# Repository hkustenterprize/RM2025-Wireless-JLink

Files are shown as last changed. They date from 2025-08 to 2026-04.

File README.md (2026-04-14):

# 基于嵌入式 Linux 的无线 JLink 烧录器
Wireless JLink-OB based on Allwinner V3S
基于全志科技 V3S 的无线 JLink-OB 烧录器. **完美支持 Ozone, Keil, STM32CubeIDE 等开发软件.**
在网络状态良好情况下, Ozone 内最多可以以 1KHZ Graph 3-4 个变量. 或者以 5Hz 刷新率观测约 50 个值.

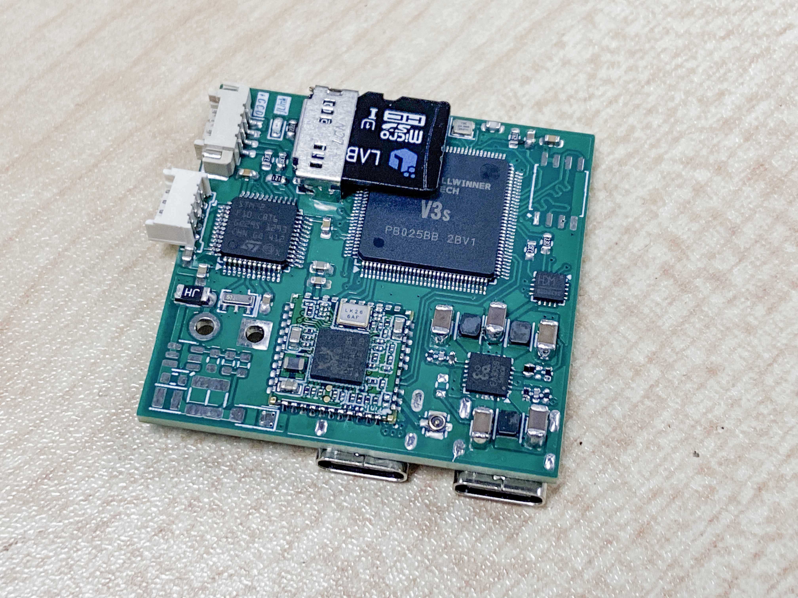
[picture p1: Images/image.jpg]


实现原理: 在 V3S 上运行自编译的 Linux 系统, 并运行 JLinkRemoteServer 共享挂载在 V3S USB 上的 JLink-OB. 板卡通过 RTL8723 SDIO 网卡联网, 处于同一局域网的电脑可通过输入无线烧录器的 IP 地址进行连接.

**主要参数**
|参数||
|:--|:--|
|尺寸|41x39x5mm|
|JLink版本|JLink-OB|
|接口|4线 SWD接口|
|无线连接距离|5-10m|

**硬件选型**
|参数||
|:--|:--|
|JLink MCU|STM32F103CB|
|嵌入式 Linux Soc|全志 V3S|
|网卡型号|RTL8723|
|电源管理芯片|EA3059|

**电源树**
系统电源较为复杂, 共有 +24V, +5V, +3V3, +3V0, +1V8, +1V2 几种不同电压. 主要由 EA3059 (或 EA3059C) 产生. 其中, V3S 内部供电由蓝色标出, 板上其他外设供电由黄色标出.
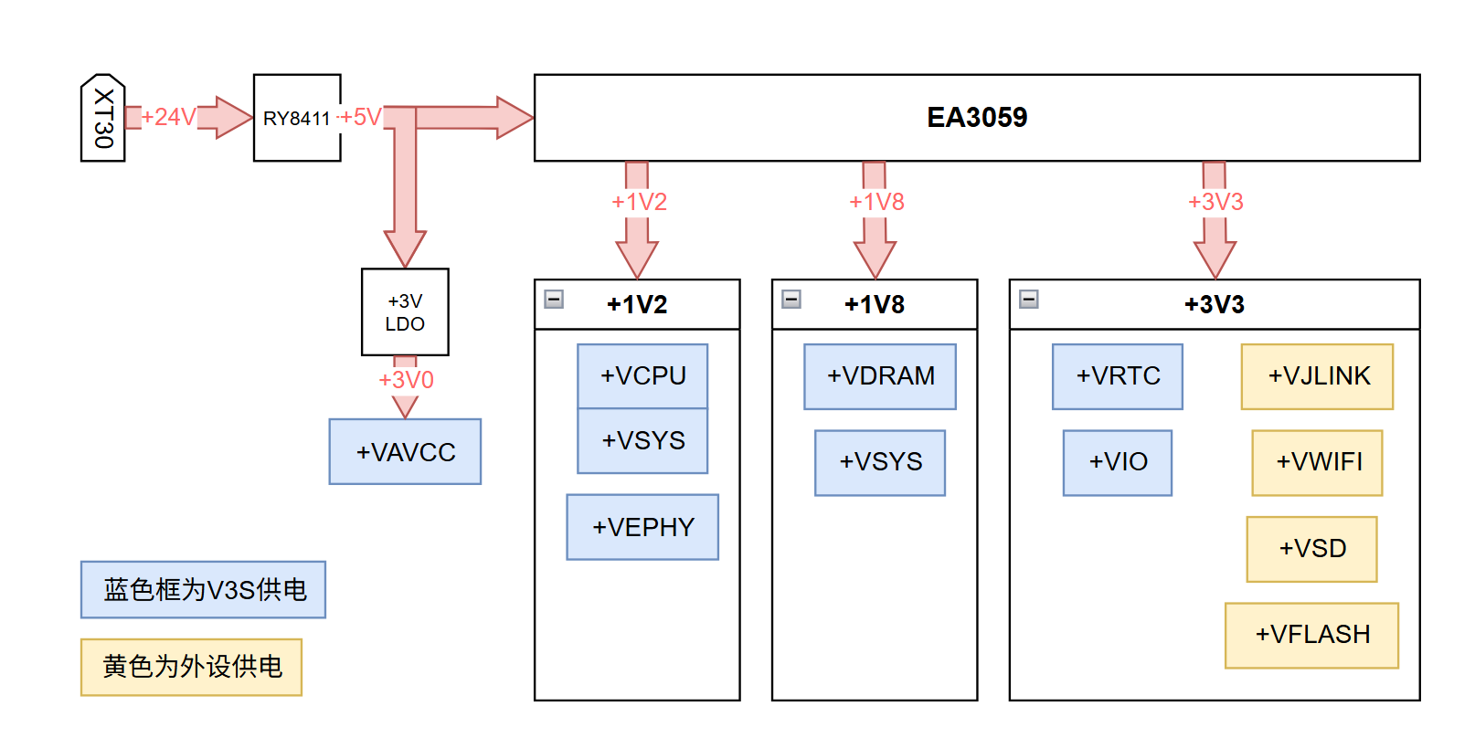
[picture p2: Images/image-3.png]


**硬件框图**
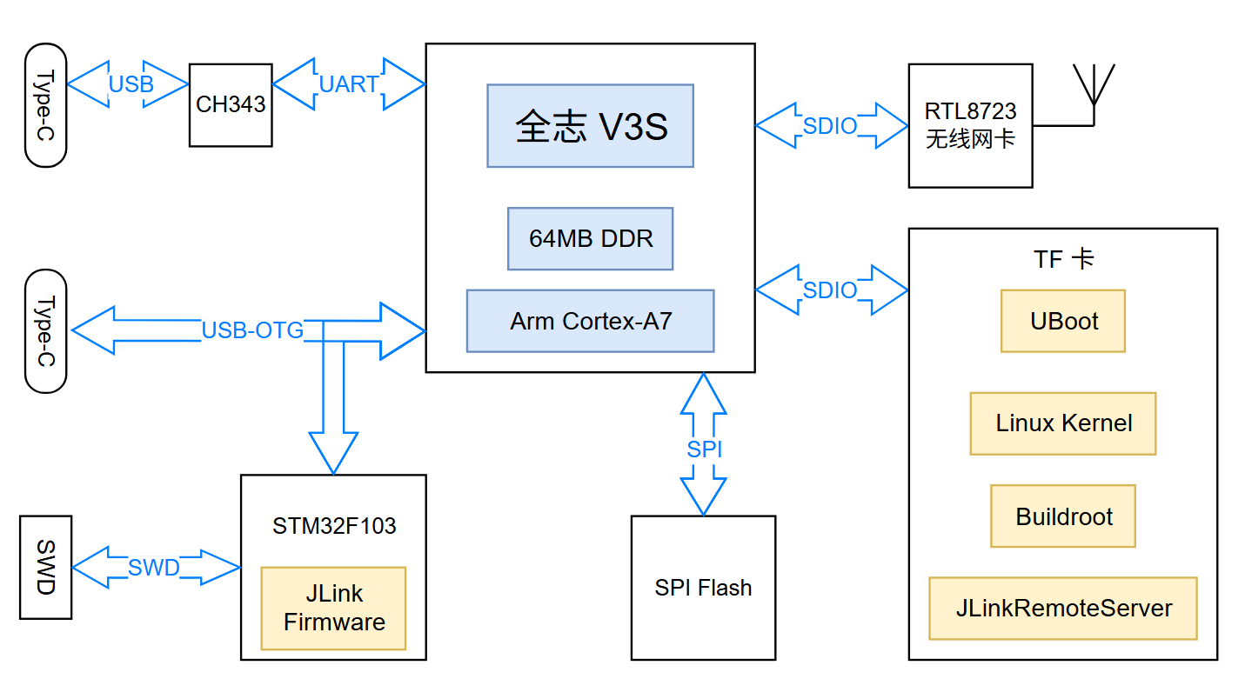
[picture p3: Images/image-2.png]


# 使用方法
> 请注意, 当前版本 SWD 接口的引脚定义与常见 SWD 引脚定义相反. 是笔者的设计失误. 请使用同向 1.25mm 同向线或手动修正线序.

1. 根据下文的固件烧录方法, 烧录 JLink 与 TF 卡固件. 并将 TF 卡插入板子上的 TF 卡座.
2. 电脑打开串口调试助手, 用 Type-C 线连接电脑与 **板子上标有 UART 的 Type-C 座**, 在串口调试助手上打开 CH343 串口. **波特率选择 115200, 数据位 8, 停止位 1, 校验位 None, 无流控**
3. 若硬件一切正常, 固件烧录正确, 将会看到串口调试助手输出以下内容:

```
U-Boot 2017.01-rc2-00057-g32ab1804cd (Sep 30 2024 - 18:54:30 +0800) Allwinner Technology

CPU:   Allwinner V3s (SUN8I 1681)
Model: Lichee Pi Zero
DRAM:  64 MiB

...
Found U-Boot script /boot.scr
reading /boot.scr
...
Starting kernel ...

[    0.000000] Booting Linux on physical CPU 0x0

...
Welcome to ENTERPRIZE buildroot.
```

实际输出可能与给出的示例略有差别, 以打印出 Welcome to ENTERPRIZE buildroot. 为一切正常的标准.
此时的界面为 Linux 命令行登录界面. 账号为 **root**, 密码为 **baoqi**

**Wifi 配置**
首次启动成功后, 请参照如下步骤连接 wifi. 需要注意的是, 路由器需要选择 WPA-EAP/WPA-PSK 加密方式. 其他加密方式需要对应修改 /etc/wpa_supplicant.conf 且笔者实测兼容性较差, 在部分路由器出现认证失败问题无法联网.

1. 编辑 /etc/wpa_supplicant.conf
```conf
ctrl_interface=/var/run/wpa_supplicant
ctrl_interface_group=0
ap_scan=1
network={
    ssid="Your SSID"
    scan_ssid=1
    key_mgmt=WPA-EAP WPA-PSK IEEE8021X NONE
    pairwise=TKIP CCMP
    group=CCMP TKIP WEP104 WEP40
    psk="Your Wifi Password"
    priority=5
}
```

2. 打开 /etc/init.d/wirelessJLinkAutoScript.sh, 并取消相关注释, 最终结果为:
```bash
#!/bin/sh
insmod /lib/modules/r8723bs.ko
ifconfig wlan0 up
wpa_supplicant -B -c /etc/wpa_supplicant.conf -i wlan0
sleep 3s
udhcpc -i wlan0
/root/JLinkARM/JLinkRemoteServerCLExe
```
3. 重启板子, 此时通过串口调试助手观察, 应该会打印出板子对应 IP, 需要并记录此 IP. 同时会显示 Waiting for client connections.. 相关文字, 代表 J-Link Remote Server 已经正常运行.
4. 通过 **交叉 1.25 4Pin 线** 连接无线烧录器 SWD 输出口与目标板.
> 请注意, 当前版本 SWD 接口的引脚定义与常见 SWD 引脚定义相反. 是笔者的设计失误. 请使用同向 1.25mm 同向线或手动修正线序.

5. 以 Ozone 为例, 在同一个局域网内, 输入无线烧录器的 IP 地址即可连接目标板.
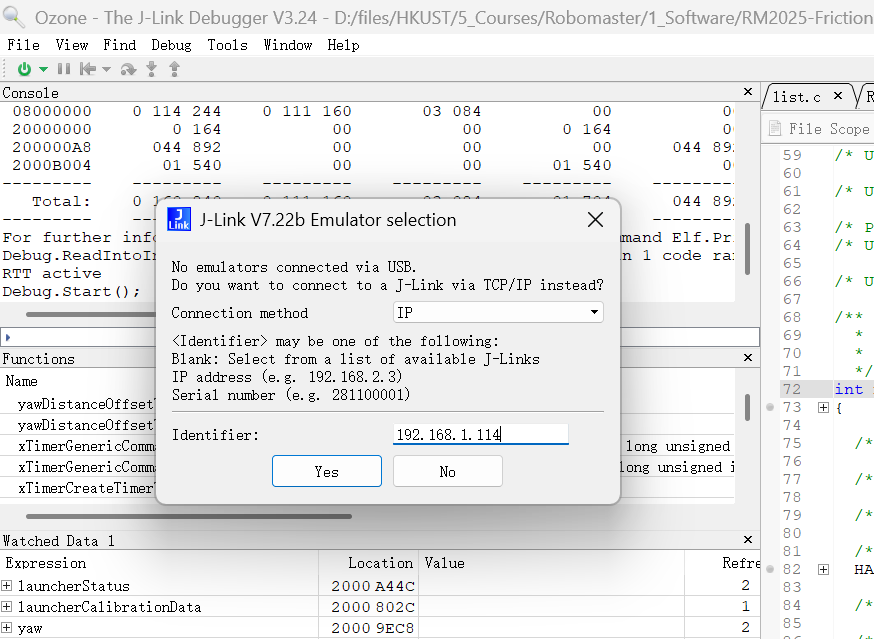
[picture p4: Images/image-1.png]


> 无线烧录器在车上使用时需要通过 Type-C 或者 XT30 供电. 经测试, 若目标板 SWD 接口有反向供电功能, 不对无线烧录器额外供电也能进行烧录, 但为确保使用稳定性, 仍建议对无线烧录器进行单独供电.

# 固件烧录
目前仅提供 TF 卡烧录相关二进制以及 TF 卡固件编译教程, SPI NOR Flash 镜像仍在调试中. 板子上的 SPI NOR Flash 可以不焊.
> 固件将与编译教程仍在整理中, 将稍后一同开源

**JLink 固件烧录**
参见笔者另一个开源 [【RM2025-地表最小 JLink 开源】香港科技大学 ENTERPRIZE 战队](https://bbs.robomaster.com/article/760967) 中给出的固件以及烧录方法.

**TF 卡固件烧录**
TF 卡要求: 容量 >= 256MByte. 读写速度无要求.
提供完整的固件 dump, 在 ./Firmware/RM2025-WirelessJLink.zip 作为参考. 其 dts, Kernel 等部分可直接复制使用.
Linux 下解压后直接用 dd 命令烧录 ./Firmware/RM2025-WirelessJLink.bin 到 TF 卡.
注意烧录 ./Firmware/RM2025-WirelessJLink.bin 之后需要手动修改网卡 ID 才能正常联网. 具体可根据自动脚本联网时的报错信息自行搜索解决.

# 固件编译
请参考 [固件编译教程](./Docs/LinuxCompileGuide.md)
其中详细地介绍了如何在 
- [荔枝派 UBoot](https://github.com/Lichee-Pi/u-boot/tree/v3s-current)
- [主线 Linux 内核](https://github.com/torvalds/linux) 
- [主线 Buildroot](https://buildroot.org/downloads/buildroot-2019.08.tar.gz)
的基础上一步步配置并编译出我们所需的 UBoot, 最简 Linux Kernel, 最简 Buildroot.

其中也包含了对全过程工具链, 启动流程, 配置思路, Linux 内核设备树, 关于 JLinkRemoteServer 的研究, RTL8723 无线网卡驱动配置, 固件加载等诸多基础内容的介绍.
凝聚了笔者全过程的踩坑经验, 或许是入门嵌入式 Linux 不错的参考.

# 未来更新
已知的硬件 bug:
- SWD 接口的引脚定义与常见 SWD 引脚定义相反. 是笔者的设计失误. 请使用同向 1.25mm 同向线或手动修正线序.

未来版本中会做如下更新:
- 增加锂电池充放电管理, 使之不再依赖于外部供电
- 修改 JLink 相关电路, 缩小体积
- 减少 V3S 滤波电容, 缩小体积

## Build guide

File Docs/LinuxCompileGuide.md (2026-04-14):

# V3S 简介与固件编译教程

[TOC]

# 引文
本教程第一部分是嵌入式 Linux 综述, 简要对比介绍主流开发板的方案, 并简述嵌入式 Linux 的开发逻辑. 第二部详细展开 **全志 V3S** 的开发流程与技术细节. 

---

**嵌入式 Linux 主流方案介绍** 时下, 树莓派, 香橙派, 荔枝派, 香蕉派等开发板市场呈现出 **百花齐放** 的繁荣景象. 其中, 基于树莓派 Raspberry Pi, 瑞芯微 Rockchip, 全志 Allwinner, 晶晨 Amlogic 等厂商 SoC 的开发板最为丰富. 此外, 主流开发板也有 ESP32, K210 等. 主要差异对比如下:

**Linux 开发板**
| 厂商 | 代表 SoC  | 性能定位 | 典型开发板 | 特点 |
|--|--|--|--|--|
|树莓派 Raspberry Pi| 博通 BCM27xx | 中高端 (1.5-2GHz) | 树莓派 4/5 | 生态优秀, 社区活跃 |
|瑞芯微 Rockchip| RK3588, RK3506 | 高端 (~2.4GHz) | Radxa ROCK 5B | 高性能视频编解码, NPU |
|全志 Allwinner| H616/D1/F1C200s/V3S | 中低端 (1.5-1.8GHz)| 香橙派, 荔枝派 | 生态较好, 社区适配完善 |
|晶晨 Amlogic| A311, S905 | 中端 (~2.0GHz) | Khadas VIM3 | 高性能 NPU, 视频处理. 生态一般. |

**RTOS 开发板**
| 厂商 | 代表 SoC  | 性能定位 | 典型开发板 | 特点 |
|--|--|--|--|--|
| 乐鑫 Espressif | ESP32 | 边缘无线通信 (240MHz) | 安信可 ESP 模块 | Wi-Fi/蓝牙双模, 高性价比 |
| 嘉楠科技 | K210 | 边缘AI (400MHz) | CamMV, MaixCAM | KPU神经网络加速, 边缘视觉 |

---

其中, 全志系列 soc 生产年份较早, 开源社区适配完善. 且全志推出了部分高性能且硬件友好的甜品款 SoC, 例如 F1C200s, V3s, V831, V851s, 其内部集成了 DDR 内存, 无须外部高速布线; 不采用 BGA 封装, 焊接友好, 4 层甚至 2 层板即可布下. 我们的最终目标是运行 JLinkRemoteServer, 并尽可能选择便宜低端的 SoC. F1C200s 没有 FPU 无法运行 JLinkRemoteServer, V831 已停产价格高. V3s 在某二手平台上价格为 10元/片 拆机带板. 因此笔者选择了 V3s. 

**全志 V3s** 封装内内有一个 ARM Cortex-A7 CPU(32 位) 以及 64MB DDR 内存. 特色是包含 CSI 相机接口, 与 RGB 屏幕接口. 设计之初主要应用于相机类产品, 如行车记录仪, 摄像头, 卡拉 OK 中控等. 沿用此思路, V3S 可成为飞镖视觉制导/无线调参方案之一. 但受限于 Linux 平台开发难度, 未进行进一步研发.

软件开发方面, V3S 基于 ARM Cortex 架构, 因此其开发方式与 STM32 有诸多相似之处. 本教程也将与 STM32 开发流程进行对比解析, 以方便了解 STM32 嵌入式开发技术的同学快速入门. 软件适配上主要有全志官方 Camdriod SDK, 主线 Linux, 第三方 XBoot 等裸机框架等丰富选择. 下面是对其简要的介绍.

|软件框架|简介|
|--|--|
|全志官方 Camdriod SDK|内核版本 3.4, 官方主推, 摄像头驱动适配好, 但开发资料少|
|主线 Linux|资料丰富但复杂度高|
|XBoot 等裸机框架|与 STM32 开发高度相似, 但社区支持较差, 无法直接运行 JLinkRemoteServer|

> **名词解释**
> 主线 Linux: 主要指主线内核 https://github.com/torvalds/linux, 是不同发行版修改的源头, 是 Linux 内核的主干与官方发布.
> 裸机: 没有操作系统, 直接运行程序.

笔者选择在 V3S 上运行 **主线 Linux**, 主要是出于学习目的与信仰.

# V3S
**参考资料列表**
- [荔枝派官方资料](https://wiki.sipeed.com/soft/Lichee/zh/Zero-Doc/System_Development/uboot_build.html)
- [CSDN RTL8723 Wifi 模块配置教程](https://blog.csdn.net/qq_28877125/article/details/125092933)

# 软件框架
固件主要包含三个部分, UBoot, Linux Kernel, Buildroot. 
- **UBoot** 为 bootloader, 其功能是初始化 ddr, 初始化时钟等. 同时, UBoot 会从引导介质, 如 TF 卡, SPI Flash, NAND Flash 等处搜索可启动的介质, 并从中加载 Kernal 并运行. 同时也会向内核传递一些启动参数. 详见后文 Uboot 编译部分.
- **Kernel** 即内核, 本质是一个巨大的程序. 负责管理计算机硬件资源, 并为应用程序提供接口.
- **Buildroot** 用来构建根文件系统. 即构建我们在根目录下看到的 /var, /opt 等文件夹. 

你可以跟着下文一步步进行配置编译与烧录.

相关链接:
- [荔枝派 UBoot](https://github.com/Lichee-Pi/u-boot/tree/v3s-current)
- [主线 Linux 内核](https://github.com/torvalds/linux) 
- [主线 Buildroot](https://buildroot.org/downloads/buildroot-2019.08.tar.gz)

# 环境配置
本教程基于 Ubuntu 22.04(x86_64) 平台. 笔者实测 WSL, 虚拟机也可正常编译但速度奇慢. 在 13900 平台上全量 rebuild 需要约 20 分钟.

安装编译所需的基本依赖
```bash
sudo apt install git wget make gcc flex bison libssl-dev bc kmod
```

安装 **交叉编译工具链**. 编译平台架构是 x86_64, 与目标架构是 ARM 不同, 因此需要使用交叉编译器. 这一点与 STM32 开发同理, STM32 常见编译器有 Keil 的 ARM Compiler, gcc 系列的 arm-none-eabi- 工具链. 对于此处应用, 我们选择 **arm-linux-gnueabihf** 工具链. 工具链名称中 arm 代表目标架构是 arm, linux 代表可编译在 linux 操作系统上运行的二进制. 此编译器也可编译无操作系统的裸机程序. gnueabihf 全称为 The GNU C compiler for armhf architecture. armhf 中的 hf 意为 hardware floating point, 即硬件 浮点处理器(FPU). V3S 内部有 FPU, 所以我们应当选择 arm-linux-gnueabihf 而非 arm-linux-gnueabi(无法生成 FPU 相关指令)
> 具体命名细节可参考 [CSDN 交叉编译器的命名规则及详细解释](https://blog.csdn.net/LEON1741/article/details/81537529)

> **名词解释**
> 编译器 Compiler: 狭义的编译器只负责编译过程. 
> 工具链 ToolChain: 包括编译器, 链接器 Linker, 调试器 Debugger 等开发全流程所需的工具合集.

我们选择 6.3.1-2017.05 版本的 arm-linux-gnueabihf-gcc. 即 gcc-linaro-6.3.1-2017.05-x86_64_arm-linux-gnueabihf.tar.xz

工具链网址 https://releases.linaro.org/components/toolchain/binaries/6.3-2017.05/arm-linux-gnueabihf/
使用如下命令下载安装工具链:
```bash
wget https://releases.linaro.org/components/toolchain/binaries/6.3-2017.05/arm-linux-gnueabihf/gcc-linaro-6.3.1-2017.05-x86_64_arm-linux-gnueabihf.tar.xz
tar xvf gcc-linaro-6.3.1-2017.05-x86_64_arm-linux-gnueabihf.tar.xz
sudo mv gcc-linaro-6.3.1-2017.05-x86_64_arm-linux-gnueabihf /opt/
sudo vi /etc/bash.bashrc
# 添加到末尾: PATH="$PATH:/opt/gcc-linaro-6.3.1-2017.05-x86_64_arm-linux-gnueabihf/bin"
source /etc/bash.bashrc
arm-linux-gnueabihf-gcc -v
sudo apt-get install device-tree-compiler
```

我们选择将工具链放在 /opt/ 下, 也可放在任何你想要的位置. 注意对应修改 PATH 变量.

# 固件编译
建议新建一个文件夹, 如 ~/V3S 用于存储相关的项目文件夹.

## UBoot
V3s 相关启动代码(ddr 内存, 时钟等初始化)似乎并没有合并到主线 U-Boot. 因此, 我们选择 [荔枝派维护的 U-Boot](https://github.com/Lichee-Pi/u-boot/tree/v3s-current)

使用如下命令 clone 到本地
```bash
git clone https://github.com/Lichee-Pi/u-boot.git -b v3s-current
```

**make menuconfig 简介**
采用 Makefile 构建的大型软件通常使用 menuconfig 可视化调整参数. 如下命令可以进入 menuconfig 界面, 注意需要保持命令行窗口足够大以显示 GUI 界面:
``` bash
cd u-boot
make ARCH=arm menuconfig
```

什么是 menuconfig: 是一个基于 **文本界面** 的配置工具, 终端的字符由文本绘制而成. make 通过读取目录下 **Kconfig** 文件, 并根据 Kconfig 的描述内容生成一个图形化参数配置界面. 当保存退出之后, 配置文件会保存在目录下的 **.config** 文件中.
- 使用上下左右方向键可移动光标, 回车进入, ESC 返回上一级菜单或退出.
- 对于 checkbox 类型配置, 使用空格键切换启用功能或禁用功能:
- [ ]/< >: 该功能未被启用. 
- [\*]/<\*>: 该功能将被编译进内核. 
- [M]: 该功能将被编译为独立的模块. 

---

荔枝派维护的 U-Boot 主要往 U-Boot 添加了驱动代码与默认 config. 我们使用如下命令使用荔枝派给出的默认 config:

```bash
make ARCH=arm CROSS_COMPILE=arm-linux-gnueabihf- LicheePi_Zero_defconfig
```

在荔枝派默认 config 基础上, 我们要做如下的修改:

最后, 我们编译 U-Boot:

```bash
make ARCH=arm CROSS_COMPILE=arm-linux-gnueabihf- -j8
```

> -j8 可自由选择编译的最大线程数. 指定为 -j 为不限制.

### Boot arguments
上文提到, U-Boot 也负责将内核加载到内存, 负责向内核传递启动参数. 具体地说, 我们需要告诉 U-Boot 将内核文件, 设备树在哪里, 需要内核加载到哪个内存地址上. 告诉内核将启动信息显示在哪里(如串口或者屏幕上), 
> **名词解释**
> 设备树: 描述一款 CPU 外设配置与板级硬件配置的信息. 内核中的硬件驱动会读取设备树文件. 可以暂时略过, 后文会详细讨论.

可以在 U-Boot 的 menuconfig 里设置这些启动参数, 但需要修改这些参数则需重新编译烧录 U-Boot 较为麻烦.

我们在这里不修改 boot-args 和 boot-cmd, 我们选择生成一个 boot.scr 文件, 然后直接用文件管理器复制到制定分区, 而不作为 uboot 的一部分编译到 u-boot 里. 这两个参数是环境变量, 作用是告诉 uboot 在什么地址加载内核和文件树. U-Boot 会在你的第一启动分区（fat32/exfat）中寻找boot.scr文件, 作为启动参数选项. 在这个文件中, 可以定义一些给内核传递的参数, 以及文件加载及启动的命令选项
```bash
setenv bootargs console=ttyS0,115200 root=/dev/mmcblk0p2 rootwait panic=10 earlyprintk rw
load mmc 0:1 0x41000000 zImage
load mmc 0:1 0x41800000 sun8i-v3s-licheepi-zero.dtb
bootz 0x41000000 - 0x41800000
```

### Trouble Shooting
make menuconfig 时可能会报错 fatal error: curses.h: No such file or directory, 则需要安装支持环境:

```bash
sudo apt-get install libncurses5-dev libncursesw5-dev
```

## TF 卡分区
建议使用 256MByte 或以上的 TF 卡. 需要将 TF 卡分区并格式化为如下分区形式:

共分三个部分: 
1. 预留 10MB 的未分配空间, 用于存储 U-Boot. 需要使用 dd 命令将 U-Boot 直接写入指定区域. V3S 在启动过程中会读取固定的地址判断 TF 卡是否有可启动的固件.
2. **第一分区**: 大小为 11MByte. FAT16 文件系统. 用于存储 boot.scr, linux kernel, .dtb. 
3. **第二分区**: 剩余所有的是 EXT4 分区, 用于存储 rootfs. 

注意, TF 卡分区过程中会清除所有数据. 请谨慎操作. 相关命令如下:

```bash
# 根据实际 mount 到的位置调整
umount /dev/sdb
umount /dev/sdb1

sudo fdisk /dev/sdb
# 新建分区, 依次按如下的键
n p 1(默认) 10240 +11M
n p 2(默认) 32768 默认

# 退出
w
```

最后得到如下两个分区: 
设备       启动  起点     末尾     扇区  大小 Id 类型
/dev/sdb1       10240    32767    22528   11M 83 Linux
/dev/sdb2       32768 15359999 15327232  7.3G 83 Linux

---

格式化分区: 
```bash
sudo mkfs.vfat /dev/sdb1 # 将第一分区格式化成 FAT
sudo mkfs.ext4 /dev/sdb2 # 将第二分区格式化成 EXT4
```

**烧录命令**
```bash
# 烧录 U-Boot
sudo dd if=~/V3S/u-boot/u-boot-sunxi-with-spl.bin of=/dev/sdb bs=1024 seek=8

# 烧录 rootfs
# 查看磁盘名称
df -h 
# 把 buildroot 产生的 rootfs.tar 解压到第二分区根目录
# 第二分区路径类似于: /media/yourName/51b395d3-1622-41af-aee4-0f25b7cf09d0
sudo tar xvf ~/V3S/buildroot-2019.08/output/images/rootfs.tar -C /第二分区路径

# cd 到 TF 卡内, 并直接 chmod, 防止在启动时报权限错误
cd /第二分区路径
chmod 777 R .
```

## Linux Kernel
**拉取内核**
我们使用 5.2.0 内核. 我们想使用 Lichee-Pi 配好的 Kernel Config 模版, 因此我们拉取 Lichee-Pi 的 Linux Kernel 仓库:

```bash
# 拉取 zero-5.2.y 单层分支
git clone -b zero-5.2.y --depth 1 https://github.com/Lichee-Pi/linux.git
```

使用 licheepi_zero_defconfig 作为初始的配置, 并可根据需要修改其他配置.
```bash
make ARCH=arm CROSS_COMPILE=arm-linux-gnueabihf- INSTALL_MOD_PATH=out licheepi_zero_defconfig
make ARCH=arm CROSS_COMPILE=arm-linux-gnueabihf- INSTALL_MOD_PATH=out menuconfig
```

**修改内核配置以支持无线网卡**
在 menuconfig 内, 可修改打进内核的驱动, 网卡驱动等.

```bash
make ARCH=arm CROSS_COMPILE=arm-linux-gnueabihf- INSTALL_MOD_PATH=out menuconfig
```

1. 使能无线相关配置
注意, 这两个在 licheepi_zero_defconfig 里是以 Module 形式存在的 `[M]` , 我们把它打包进内核 `[*]`
```
Networking support
	Wireless
		[*] cfg80211 - wireless configuration API
		[*] Generic IEEE 802.11 Networking Stack (mac80211)
```

2. 使能 rtl8723 驱动
使用 licheepi_zero_defconfig 时已经使能了 rtl8723 驱动了. 
需要注意的是, rtl8723 必须以模块 Module 的形式编译, 形成 .ko 文件, 然后手动复制到根文件系统, 并在启动后使用 insmod 加载.
编译命令:

```bash
make ARCH=arm CROSS_COMPILE=arm-linux-gnueabihf- INSTALL_MOD_PATH=out -j16 modules
make ARCH=arm CROSS_COMPILE=arm-linux-gnueabihf- INSTALL_MOD_PATH=out -j16 modules_install
```

编译出来的 r8723bs.ko 在：
./linux/out/lib/modules/5.2.0-licheepi-zero+/kernel/drivers/staging/rtl8723bs/r8723bs.ko
后文会将此文件放到根文件系统内.

**修改设备树**
我们在 sun8i-v3s-licheepi-zero-dock.dts 的基础上进行修改.
`[TODO]` 具体如何修改 dts

**编译内核**
```bash
make ARCH=arm CROSS_COMPILE=arm-linux-gnueabihf- INSTALL_MOD_PATH=out -j16
make ARCH=arm CROSS_COMPILE=arm-linux-gnueabihf- INSTALL_MOD_PATH=out -j16 modules
make ARCH=arm CROSS_COMPILE=arm-linux-gnueabihf- INSTALL_MOD_PATH=out -j16 modules_install
make ARCH=arm CROSS_COMPILE=arm-linux-gnueabihf- INSTALL_MOD_PATH=out -j16 dtbs
```

然后手动复制如下文件到 SD 卡第一个分区:
./linux/arch/arm/boot/zImage
./linux/arch/arm/boot/dts/sun8i-v3s-licheepi-zero-dock.dtb

## Buildroot
Buildroot 用于编译出根文件系统. 在 Linux 系统上看到 / 根目录下所有的文件就是根文件系统. 包含了系统运行所需的所有外围部分.
荔枝派对此处并未做详细描述. 因此我们使用 2019.08 版本的 Buildroot 从零手动配置.

**下载 buildroot 并解压**
```bash
wget https://buildroot.org/downloads/buildroot-2019.08.tar.gz
tar xvf buildroot-2019.08.tar.gz&&cd buildroot-2019.08/
```

---

**配置 Buildroot**
```bash
make menuconfig
```

1. **配置 Target options**
```
Target options  --->
	Target Architecture (ARM (little endian))  --->
	Target Binary Format (ELF)  --->
	Target Architecture Variant (cortex-A7)  --->
	Target ABI (EABIhf)  --->
	Floating point strategy (VFPv4-D16)  --->
	ARM instruction set (ARM)  ---> 
```

2. **配置工具链 Toolchain**
1. 查看工具链地址： which arm-linux-gnueabihf-g++
/opt/gcc-linaro-6.3.1-2017.05-x86_64_arm-linux-gnueabihf/bin
然后填入/opt/gcc-linaro-6.3.1-2017.05-x86_64_arm-linux-gnueabihf

2. 查看 arm-linux-gnueabihf 版本
/opt/gcc-linaro-6.3.1-2017.05-x86_64_arm-linux-gnueabihf/bin/arm-linux-gnueabihf-gcc --version
得到 6.3.1

3. 查看 Linux kernel headers 版本： /opt/gcc-linaro-6.3.1-2017.05-x86_64_arm-linux-gnueabihf/arm-linux-gnueabihf/libc/usr/include/linux/version.h
查看到十进制的版本号为 262144, 16 进制表达为 0x40600, 则对应的内核版本号为4.6.0. 

最后结果为：
```
Toolchain  --->
	Toolchain type (External toolchain)  --->
	*** Toolchain External Options ***
	Toolchain (Custom toolchain)  --->
	Toolchain origin (Pre-installed toolchain)  --->
	(/opt/gcc-linaro-6.3.1-2017.05-x86_64_arm-linux-gnueabihf) Toolchain path
	(arm-linux-gnueabihf) Toolchain prefix
	External toolchain gcc version (6.x)  --->
	External toolchain kernel headers series (2.6.x)  --->
	External toolchain C library (glibc/eglibc)  --->
	[*] Toolchain has SSP support? (NEW)
	[*] Toolchain has RPC support? (NEW)
	[*] Toolchain has C++ support? 
	[*] Enable MMU support (NEW) 
```

3. **配置 System configuration**
Init system：这里选择busybox, 轻量级使用非常广泛. 可选的有systemV,systemd.

同时, 我们根据 buildroot 自带的 licheepi_zero_defconfig, 配置了串口
```
(RM2025) System hostname
(xxx) System banner
    Init system (BusyBox)
[*] Enable root login with password
(baoqi) Root password

[*] Run a getty (login prompt) after boot --->
    (ttyS0) TTY port
        Baudrate (115200)
```

4. **配置 Target package**

我们想使用 udevadm 工具配置 jlink usb 驱动, 所以要把 eudev 打包进 buildroot. 
进行如下修改：

```
System configuration
	/dev management (Dynamic using devtmpfs + eudev)

Target package
	Hardware Handling
		[*] eudev
		后面两个也开了
```

这样就能在运行时修改规则 rules 了

5. **配置 Filesystem images**
根据 buildroot 自带的 licheepi_zero_defconfig, 使能了 ext4 support
```
[*] ext2/3/4 root filesystem
    ext2/3/4 variant (ext4)  --->
```

6. 打开 wireless tools 和 wpa_supplicant, 使能 wpa_supplicant 所有功能以支持 Wifi 联网.

```
Target package
	Networking applications
		[*] wireless tools
		[*] 	Install shared library

		[*] wpa_supplicant
		[*]   Enable nl80211 support (NEW)                
		[*]   Enable AP mode                              
		[*]     Enable Wi-Fi Display                      
		[*]     Enable mesh networking                    
		[*]   Enable autoscan
		[*]   Enable EAP                       
		[*]   Enable HS20
		[*]   Enable syslog support
		[*]   Enable WPS      
		[*]   Install wpa_cli binary 
		[*]   Install wpa_client shared library
		[*]   Install wpa_passphrase binary 
```

---

配置完之后, 我们保存并退出 menuconfig. 执行 `make` 编译.
注意 buildroot **不支持** 多线程编译. 在 intel 13900 平台上编译用时约 20min.
编译完成后得到 ./output/images/rootfs.tar 我们把 rootfs.tar 解压到 TF 卡的第二分区:

```bash
# 烧录 rootfs
# 查看磁盘名称
df -h 
# 把 buildroot 产生的 rootfs.tar 解压到第二分区根目录
# 第二分区路径类似于: /media/yourName/51b395d3-1622-41af-aee4-0f25b7cf09d0
sudo tar xvf ~/V3S/buildroot-2019.08/output/images/rootfs.tar -C /第二分区路径

# cd 到 TF 卡内, 并直接 chmod, 防止在启动时报权限错误
cd /第二分区路径
chmod 777 R .
```

---

**在根文件目录中配置 Wifi 模块驱动**
上文我们在编译 Linux 内核过程中得到了 r8723bs.ko 驱动模块. 我们需要将其手动复制到 TF 卡的指定位置并在运行后执行命令加载它.
建议将 r8723bs.ko 复制到 TF 卡的 /lib/moduels/r8723bs.ko

```bash
cd /TF卡第二分区路径/lib
sudo mkdir modules
sudo chmod 777 ./modules
cp ~/V3S/linux/out/lib/modules/5.2.0-licheepi-zero+/kernel/drivers/staging/rtl8723bs/r8723bs.ko ./moduels
```

rtl8723 Wifi 模块没有固件存储空间, 因此每次在系统启动后, 都需要通过 SDIO 接口往 rtl8723 Wifi 模块里加载固件:
下载地址: https://github.com/ferbar/rtl8723bs/blob/master/rtl8723bs_nic.bin

将 WiFi 固件 rtl8723bs_nic.bin 拷到根文件系统分区 /lib/firmware/rtlwifi 目录下
```bash
cd /TF卡第二分区路径/lib
sudo mkdir firmware
sudo mkdir firmware/rtlwifi
sudo chmod 777 ./firmware
sudo chmod 777 ./firmware/rtlwifi

cp /rtl8723bs_nic.bin路径 ./firmware/rtlwifi
```

---

**复制 JLinkRemoteServer 到根文件系统**
在 V3S 上运行 JLinkRemoteServerCLExe 依赖以下 dll：
- libjlinkarm.so.7.98.8
- libjlinkarm.so.7          --> libjlinkarm.so.7.98.8
- libjlinkarm.so.         --> libjlinkarm.so.7.98.8

也可能需要 99-jlink.rules, 通过 usbid 来指派驱动. 启动后, 使用 lsusb 查询是否连到了 JLink. 

因此我们一共需要将如下的文件复制到 TF 卡的 /root/JLinkARM 文件夹
```
99-jlink_new.rules  JLinkRemoteServerCLExe  libjlinkarm.so    libjlinkarm.so.7.98.8
99-jlink_ori.rules  libjlinkarm.so.7        99-jlink.rules
```

## Trouble Shooting

编译 Buildroot 的时候报错 LD_LIBRARY_PATH. 是因为多了个空行.
用 LD_LIBRARY_PATH= 清空这个变量就行. 然后重新编译 Buildroot.

# 启动!
经过上述步骤, TF 卡内已经有如下三个部分:
1. 预留 10MB 的未分配空间, 存储了 U-Boot.
2. **第一分区**: 存储了 boot.scr, linux kernel, .dtb.
3. **第二分区**: 剩余所有的是 EXT4 分区, 用于存储根文件系统. 

将 TF 卡插入板子, 上电即可启动. 在板子的 UART 口会打印 U-Boot 和 Linux 内核启动的信息:

```
U-Boot 2017.01-rc2-00057-g32ab1804cd (Sep 30 2024 - 18:54:30 +0800) Allwinner Technology

CPU: Allwinner V3s (SUN8I 1681)
Model: Lichee Pi Zero
DRAM: 64 MiB
MMC: SUNXI SD/MMC: 0

...

Starting kernel ...

[    0.000000] Booting Linux on physical CPU 0x0
[    0.000000] Linux version 5.2.0-licheepi-zero+ (baoqi@baoqi) (gcc version 9.4.0 (Ubuntu 9.4.0-1ubuntu1~20.04.2)) #4 SMP Wed Oct 9 20:08:04 HKT 2024
[    0.000000] CPU: ARMv7 Processor [410fc075] revision 5 (ARMv7), cr=10c5387d
[    0.000000] CPU: div instructions available: patching division code
[    0.000000] CPU: PIPT / VIPT nonaliasing data cache, VIPT aliasing instruction cache
[    0.000000] OF: fdt: Machine model: Lichee Pi Zero

...

Welcome to ENTERPRIZE buildroot.
```

如果一切正常, 会输出 Welcome to ENTERPRIZE buildroot. 并提供登录界面.
根据内核配置, 账号为 root 密码为 baoqi

启动之后, 我们需要逐步加载 Wifi 内核驱动, 启动 Wifi 服务, 最后启动 JLinkRemoteServer

1. **加载内核驱动, 打开 wlan0**
在启动之后使用命令 insmod /lib/modules/r8723bs.ko 加载驱动
如下返回值就是成功：

```
# insmod /lib/modules/r8723bs.ko
[   23.931169] r8723bs: module is from the staging directory, the quality is unknown, you have been warned.
[   23.960507] RTL8723BS: module init start
[   23.964447] RTL8723BS: rtl8723bs v4.3.5.5_12290.20140916_BTCOEX20140507-4E40
[   23.971580] RTL8723BS: rtl8723bs BT-Coex version = BTCOEX20140507-4E40
[   23.978244] RTL8723BS: module init ret =0
```

然后打开 wlan0：
```bash
ifconfig wlan0 up
ifconfig
```

然后在 ifconfig 内就能看到 wlan0 正常工作了.

---

2. **修改位置, 连接WiFi**
编辑 /etc/network/interfaces 文件为:
```bash
# Configure Loopback
auto lo
iface lo inet loopback
# wlan0
auto wlan0
iface wlan0 inet dhcp
```

新建一个目录用来给 wpa_supplicant 通信
```bash
mkdir -p /var/run/wpa_supplicant
```

新建一个 .conf 文件, wpa_supplicant 连接 WIFI 的时候会从配置文件中读取账号和密码, 以及加密方式等, 所以我们再运行 wpa_supplicant 工具的时候要提前写好配置文件. 
例如 /etc/wpa_supplicant.conf 填入
```conf
ctrl_interface=/var/run/wpa_supplicant
ctrl_interface_group=0
ap_scan=1
network={
    ssid="HKUST_ENTERPRIZE"
    scan_ssid=1
    key_mgmt=WPA-EAP WPA-PSK IEEE8021X NONE
    pairwise=TKIP CCMP
    group=CCMP TKIP WEP104 WEP40
    psk="12345678"
    priority=5
}
```

然后, 使用如下命令链接 wifi
```bash
wpa_supplicant -B -c /etc/wpa_supplicant.conf -i wlan0
```

输出几个 udhcpc: sending discover 之后, 会得到
```
udhcpc: sending select for 192.168.1.231
udhcpc: lease of 192.168.1.231 obtained, lease time 43200
deleting routers
adding dns 192.168.1.1
```

即为链接成功.

---

3. **运行 JLinkRemoteServer**
```bash
/root/JLinkARM/JLinkRemoteServerCLExe
```

产生如下输出即为成功:
```
SEGGER J-Link Remote Server V7.98h
Compiled Sep 11 2024 14:33:29

'q' to quit '?' for help

Welcome to ENTERPRIZE buildroot.
1970-01-01 00:00:14 - Remote Server started
1970-01-01 00:00:14 - Connected to J-Link with S/N 771828605
1970-01-01 00:00:14 - Waiting for client connections... 
```

## 自动启动脚本
开机后, 我们希望自动连接网络, 自动打开 JLinkRemoteServer. 我们需要修改 /etc/inittab:
```bash
# 在 now run any rc scripts 后加入如下
::sysinit:/etc/init.d/wirelessJLinkAutoScript.sh
```

在 /etc/init.d 目录下新建文件 wirelessJLinkAutoScript.sh 并写入:
```bash
#!/bin/sh
insmod /lib/modules/r8723bs.ko
ifconfig wlan0 up
wpa_supplicant -B -c /etc/wpa_supplicant.conf -i wlan0
sleep 3s
udhcpc -i wlan0

/root/JLinkARM/JLinkRemoteServerCLExe
```

尝试重启, 观察是否能成功自动运行.

## 通过 Ozone 远程链接
在启动后, 会打印类似 udhcpc: sending select for 192.168.1.231 的 IP. 我们通过此 IP 访问无线烧录器.
在 Ozone 启动选择 Connections Settings 时, 将 Host Interface 选择为 IP, 并填入无线烧录器的 IP 地址即可链接.

## Trouble Shooting
如果 ifconfig wlan0 up 没有反应, 请切换到 dock 版本的设备树, dock 才有 wifi. 如果依然不行, 请检查 Wifi 模块硬件. DSI 上拉电阻必须焊上.

如果 insmod /lib/modules/r8723bs.ko 报错 Unknown, 请在内核配置打开 wireless 相关配置, 重新编译内核并替换.

如果报错 CONFIG_RFKILL, 在 Buildroot 使能 RFKILL 之后可解决.

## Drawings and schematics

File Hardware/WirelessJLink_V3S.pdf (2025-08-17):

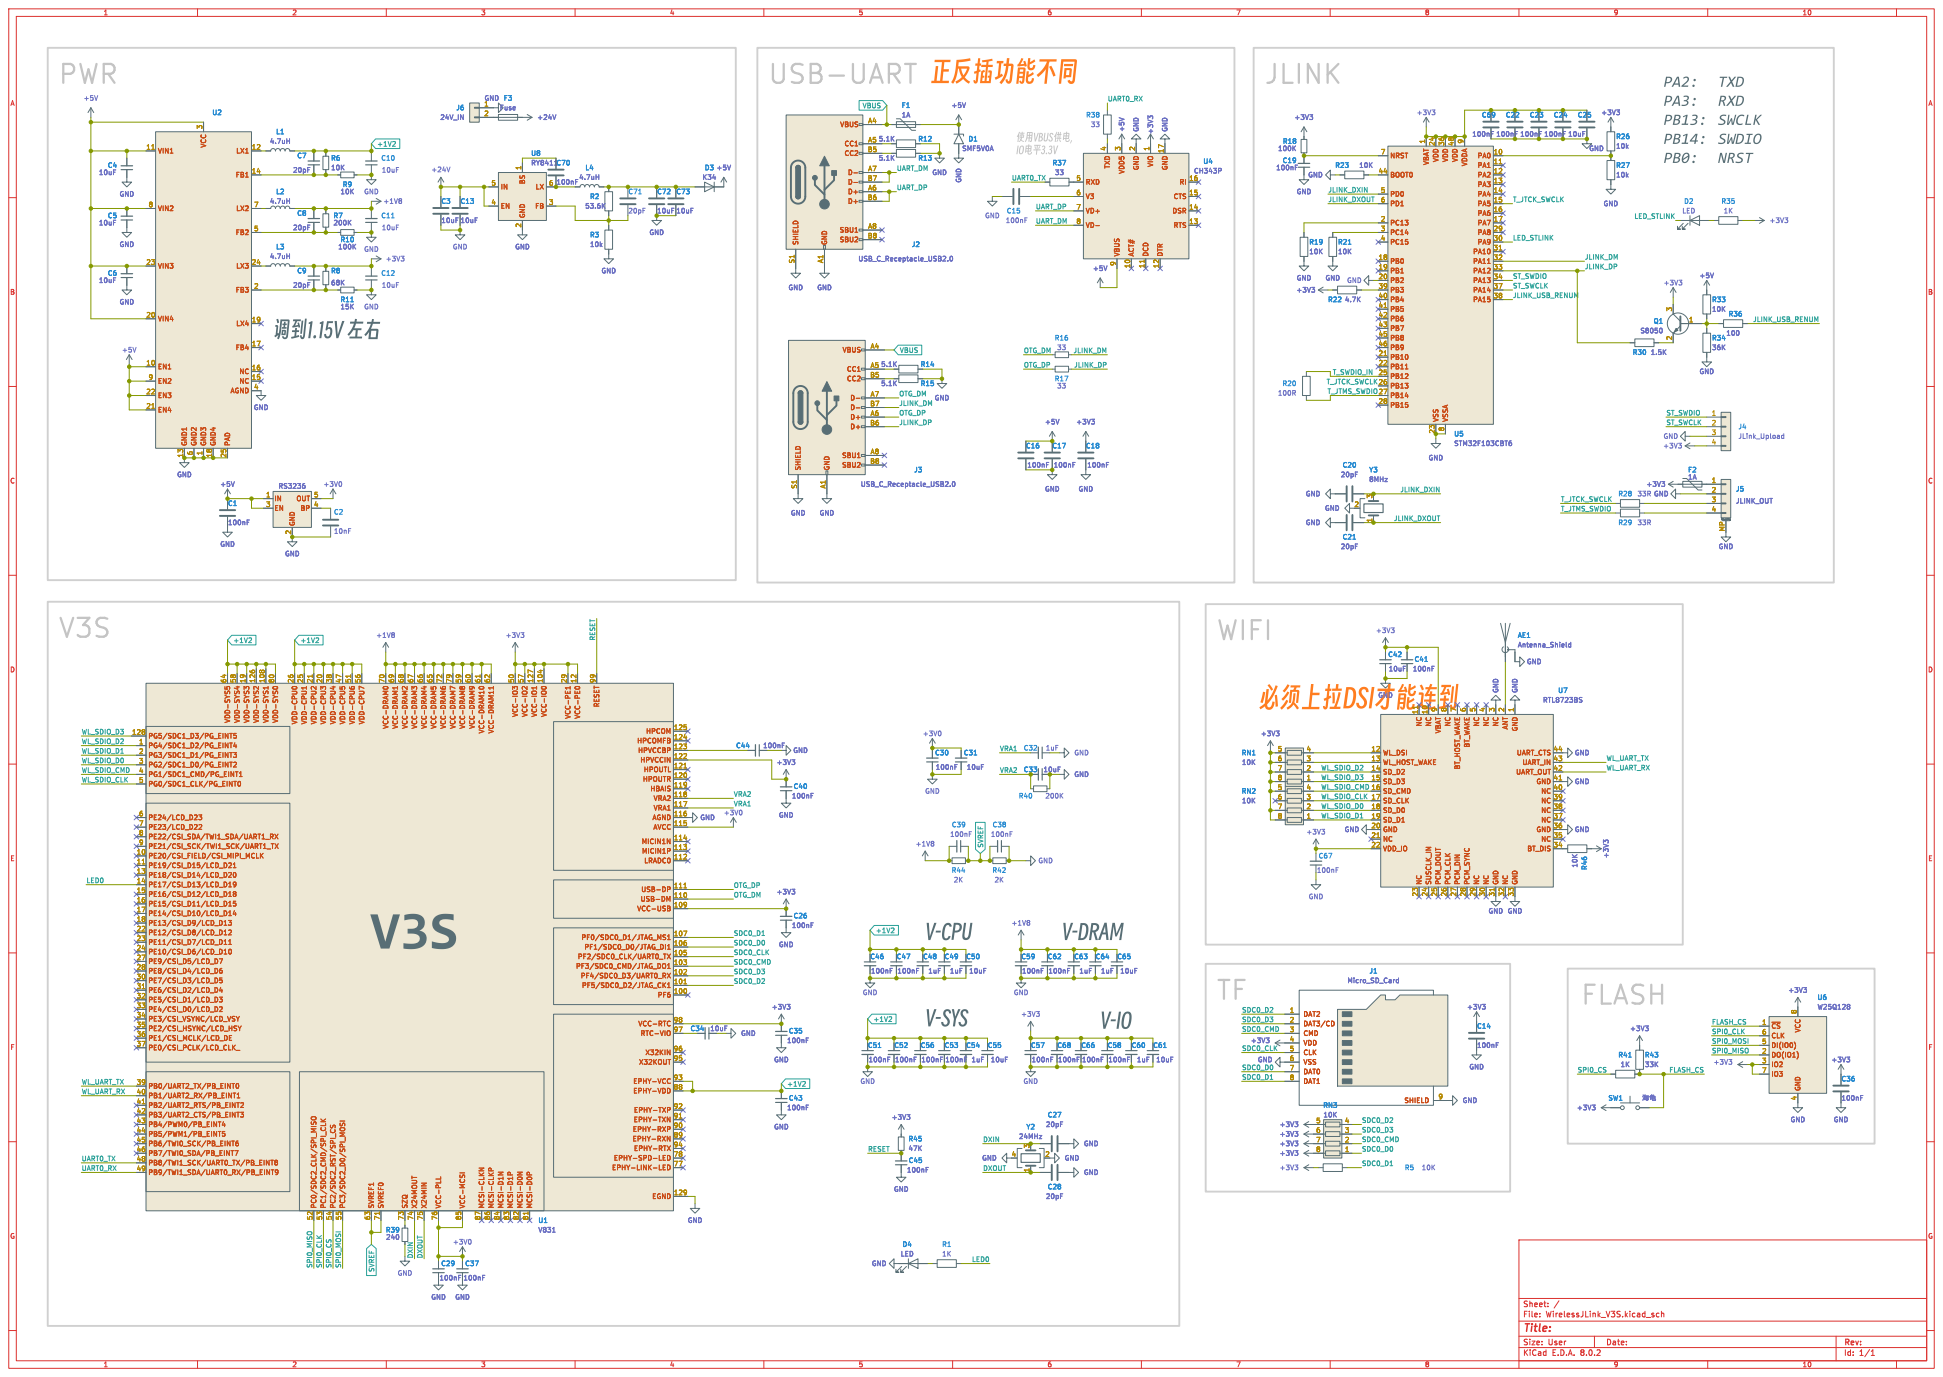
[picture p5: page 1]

1 ACT# 10 DCD 11 DTR 12 RTS 13 DSR 14 CTS 15 RI 16 GND 17 GND
LED VIO

4 RXD 5 V3 6 VD+ 7 VD- 8 VBUS

3 NC 30 GND 31 NC 32 GND 33 BT_DIS

Id: 1/1 Title: File: WirelessJLink_V3S.kicad_sch Sheet: /

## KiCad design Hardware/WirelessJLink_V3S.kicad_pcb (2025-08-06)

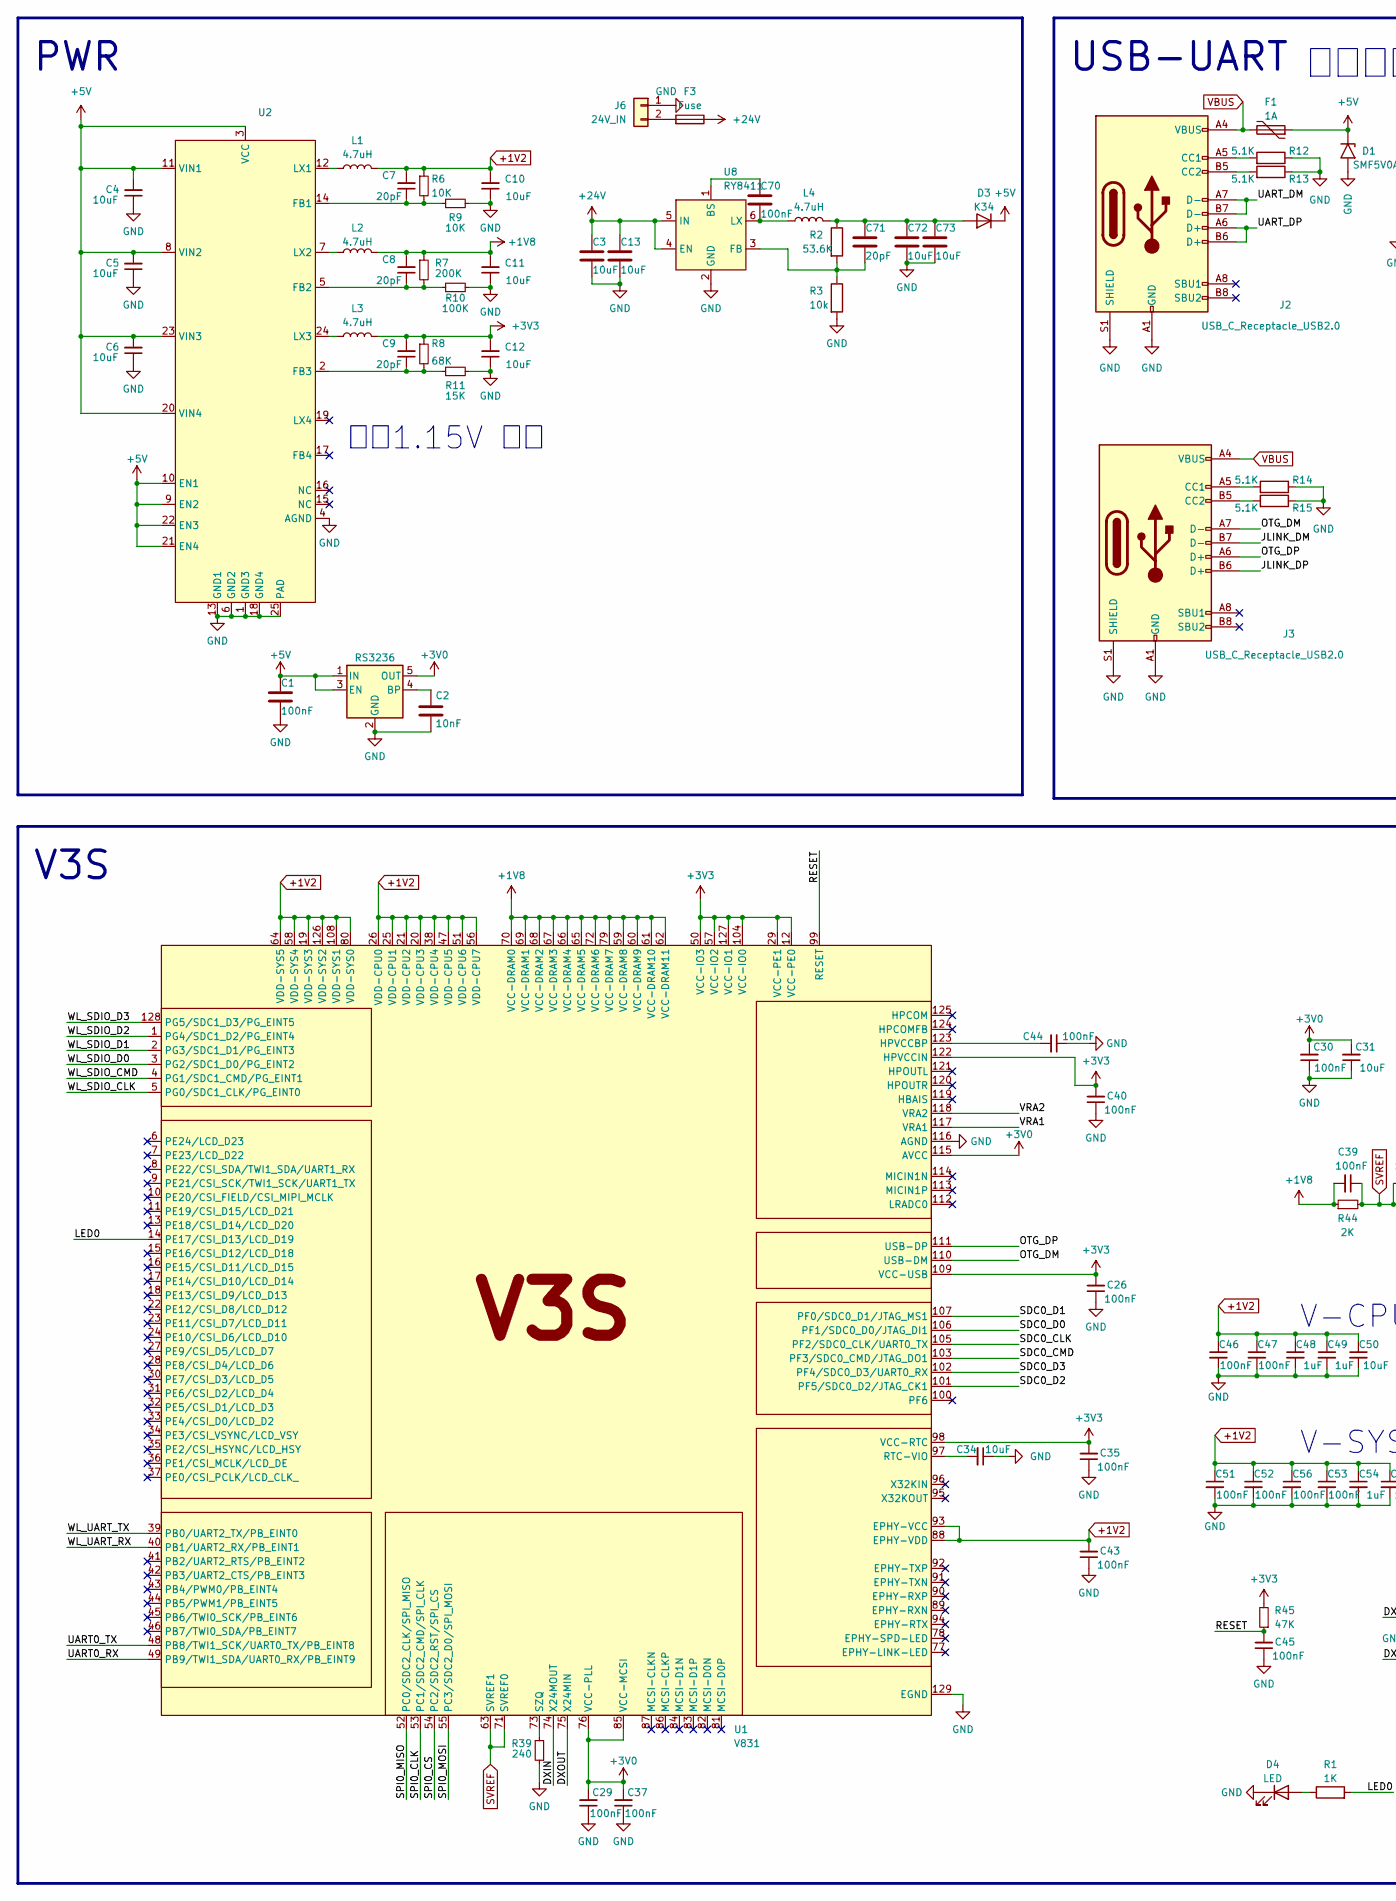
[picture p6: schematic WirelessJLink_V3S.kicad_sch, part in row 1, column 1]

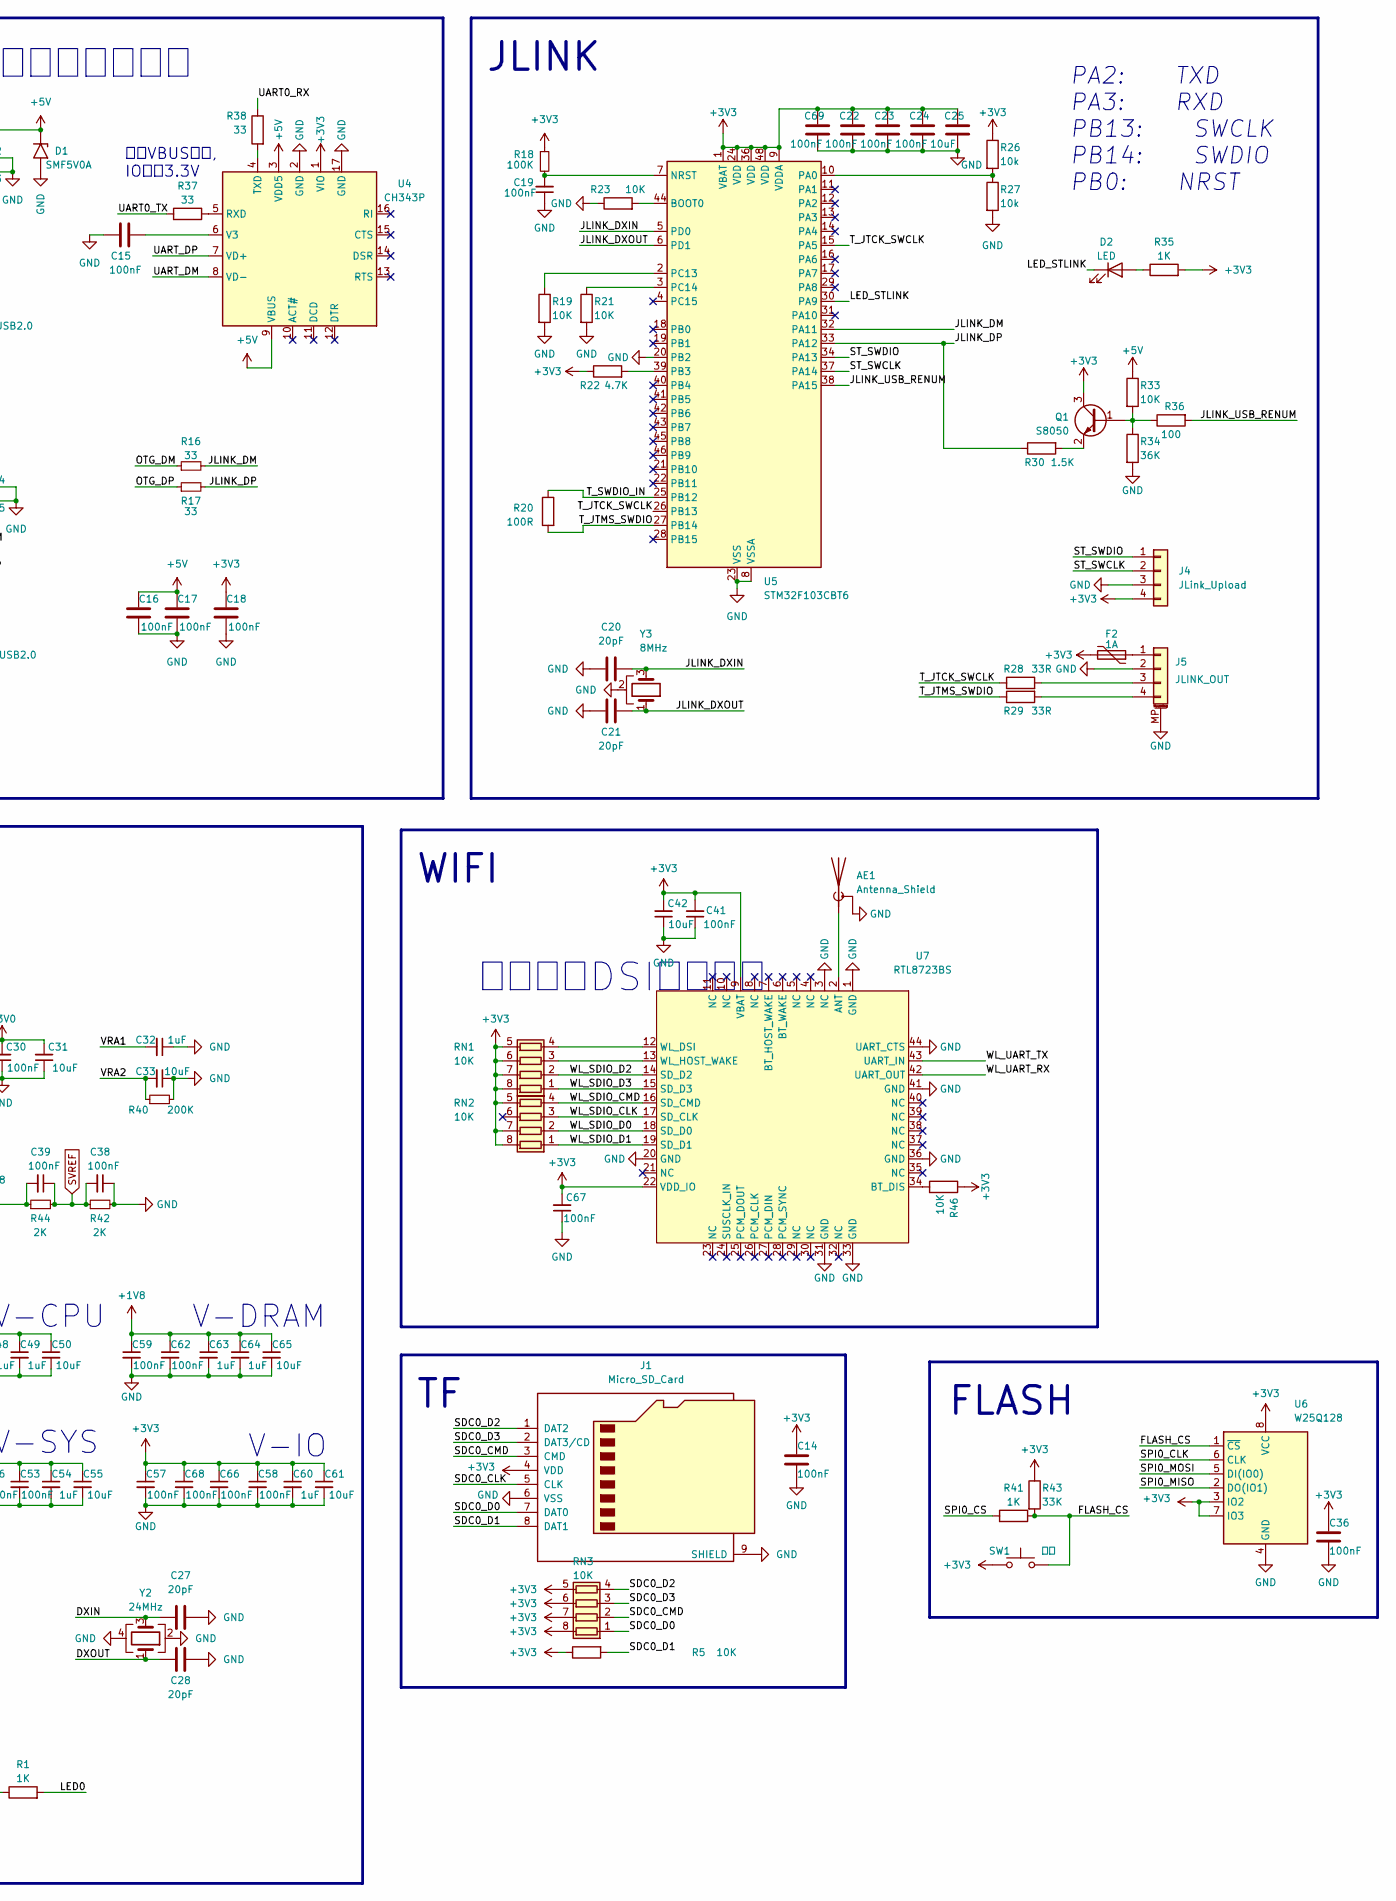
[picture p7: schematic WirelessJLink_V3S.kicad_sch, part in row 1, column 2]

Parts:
AE1: Antenna_Shield; IPXE4
C1, C14, C15, C16, C17, C18, C19, C22, C23, C24, C26, C29, C30, C35, C36, C37, C38, C39, C40, C41, C43, C44, C45, C46, C47, C51, C52, C53, C56, C57, C58, C59, C62, C66, C67, C68, C69: 100nF; C_0603_1608Metric
C2: 10nF; C_0603_1608Metric
C3, C4, C5, C6, C10, C11, C12, C13, C72, C73: 10uF; C_1206_3216Metric
C7, C8, C9: 20pF; C_0402_1005Metric
C20, C21, C27, C28: 20pF; C_0603_1608Metric
C25, C31, C33, C34, C42, C50, C55, C61, C65: 10uF; C_0603_1608Metric
C32, C48, C49, C54, C60, C63, C64: 1uF; C_0603_1608Metric
C70: 100nF; R_0603_1608Metric
C71: 20pF; R_0603_1608Metric
D1: SMF5V0A; D_SMF
D2, D4: LED; LED_0603_1608Metric
D3: K34; D_SMF
F1, F2: 1A; Fuse_1206_3216Metric
F3: Fuse; Fuse_1206_3216Metric
J1: Micro_SD_Card; TF_Card_Short2
J2, J3: USB_C_Receptacle_USB2.0; USB_C_Receptacle_HRO_TYPE-C-31-M-12_NO_HOLE
J4: JLink_Upload; Molex_PicoBlade_53048-0410_1x04_P1.25mm_Horizontal
J5: JLINK_OUT; Molex_PicoBlade_53261-0471_1x04-1MP_P1.25mm_Horizontal
J6: 24V_IN; AMASS_XT30PW-M_1x02_P2.50mm_Horizontal
L1, L2, L3, L4: 4.7uH; L_Sunlord_SWPA252012S
Q1: S8050; SOT-23
R1, R35, R41: 1K; R_0603_1608Metric
R2: 53.6K; R_0603_1608Metric
R3, R26, R27: 10k; R_0603_1608Metric
R5, R19, R21, R23, R33, R46: 10K; R_0603_1608Metric
R6, R9: 10K; R_0402_1005Metric
R7: 200K; R_0402_1005Metric
R8: 68K; R_0402_1005Metric
R10: 100K; R_0402_1005Metric
R11: 15K; R_0402_1005Metric
R12, R13, R14, R15: 5.1K; R_0603_1608Metric
R16, R17, R37, R38: 33; R_0603_1608Metric
R18: 100K; R_0603_1608Metric
R20: 100R; R_0603_1608Metric
R22: 4.7K; R_0603_1608Metric
R28, R29: 33R; R_0603_1608Metric
R30: 1.5K; R_0603_1608Metric
R34: 36K; R_0603_1608Metric
R36: 100; R_0603_1608Metric
R39: 240; R_0603_1608Metric
R40: 200K; R_0603_1608Metric
R42, R44: 2K; R_0603_1608Metric
R43: 33K; R_0603_1608Metric
R45: 47K; R_0603_1608Metric
RN1, RN2, RN3: 10K; R_Array_Convex_4x0603
SW1: 海龟; SW_Push_1P1T_NO_CK_KMR2
U1: V831; LQFP-128_14x14mm_P0.4mm
U2: HVQFN-24-1EP_4x4mm_P0.5mm_EP2.6x2.6mm_ThermalVias
U3: RS3236; SOT-23-5
U4: CH343P; TQFN-16-1EP_3x3mm_P0.5mm_EP1.6x1.6mm
U5: STM32F103CBT6; LQFP-48_7x7mm_P0.5mm
U6: W25Q128; SOIC-8_5.23x5.23mm_P1.27mm
U7: RTL8723BS
U8: RY8411; SOT-23-6
Y2: 24MHz; Crystal_SMD_2016-4Pin_2.0x1.6mm
Y3: 8MHz; Resonator_SMD_Murata_CSTxExxV-3Pin_3.0x1.1mm

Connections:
+1V2: C7.2, C10.2, C43.2, C46.1, C47.1, C48.1, C49.1, C50.1, C51.1, C52.1, C53.1, C54.1, C55.1, C56.1, L1.2, R6.1, U1.19 (VDD-SYS3), U1.20 (VDD-CPU3), U1.21 (VDD-CPU2), U1.25 (VDD-CPU1), U1.26 (VDD-CPU0), U1.38 (VDD-CPU4), U1.47 (VDD-CPU5), U1.51 (VDD-CPU6), U1.56 (VDD-CPU7), U1.58 (VDD-SYS4), U1.64 (VDD-SYS5), U1.80 (VDD-SYS0), U1.88 (EPHY-VDD), U1.93 (EPHY-VCC), U1.108 (VDD-SYS1), U1.126 (VDD-SYS2)
+1V8: C8.2, C11.2, C39.2, C59.1, C62.1, C63.1, C64.1, C65.1, L2.2, R7.1, R44.1, U1.59 (VCC-DRAM8), U1.60 (VCC-DRAM9), U1.61 (VCC-DRAM10), U1.62 (VCC-DRAM11), U1.65 (VCC-DRAM5), U1.66 (VCC-DRAM4), U1.67 (VCC-DRAM3), U1.68 (VCC-DRAM2), U1.69 (VCC-DRAM1), U1.70 (VCC-DRAM0), U1.72 (VCC-DRAM6), U1.79 (VCC-DRAM7)
+3V0: C29.2, C30.2, C31.2, C37.2, U1.76 (VCC-PLL), U1.85 (VCC-MCSI), U1.115 (AVCC), U3.5 (OUT)
+3V3: C9.2, C12.2, C14.1, C18.2, C22.1, C23.1, C24.1, C25.1, C26.2, C35.2, C36.1, C40.2, C41.2, C42.2, C57.1, C58.1, C60.1, C61.1, C66.1, C67.2, C68.1, C69.1, F2.2, J1.4 (VDD), J4.4, L3.2, Q1.3 (C), R5.1, R8.1, R18.1, R22.1, R26.1, R35.2, R43.1, R45.2, R46.1, RN1.5 (R4.2), RN1.6 (R3.2), RN1.7 (R2.2), RN1.8 (R1.2), RN2.5 (R4.2), RN2.7 (R2.2), RN2.8 (R1.2), RN3.5 (R4.2), RN3.6 (R3.2), RN3.7 (R2.2), RN3.8 (R1.2), SW1.1, U1.12 (VCC-PE0), U1.29 (VCC-PE1), U1.50 (VCC-IO3), U1.57 (VCC-IO2), U1.98 (VCC-RTC), U1.104 (VCC-IO0), U1.109 (VCC-USB), U1.122 (HPVCCIN), U1.127 (VCC-IO1), U4.1 (VIO), U5.1 (VBAT), U5.9 (VDDA), U5.24 (VDD), U5.36 (VDD), U5.48 (VDD), U6.3 (IO2), U6.7 (IO3), U6.8 (VCC), U7.9 (VBAT), U7.22 (VDD_IO)
+5V: C1.1, C4.2, C5.2, C6.2, C16.2, C17.2, D1.1 (A1), D3.1 (K), F1.1, R33.1, U2.3 (VCC), U2.8 (VIN2), U2.9 (EN2), U2.10 (EN1), U2.11 (VIN1), U2.20 (VIN4), U2.21 (EN4), U2.22 (EN3), U2.23 (VIN3), U3.1 (IN), U3.3 (EN), U4.3 (VDD5), U4.9 (VBUS)
+24V: C3.1, C13.1, F3.1, U8.4 (EN), U8.5 (IN)
/DXIN: C27.2, U1.74 (X24MOUT), Y2.3
/DXOUT: C28.2, U1.75 (X24MIN), Y2.1
/FLASH_CS: R41.1, R43.2, SW1.2, U6.1 (~CS)
/JLINK_DM: J3.B7 (D-), R16.2, U5.32 (PA11)
/JLINK_DP: J3.B6 (D+), R17.2, R30.1, U5.33 (PA12)
/JLINK_DXIN: C20.2, U5.5 (PD0), Y3.3
/JLINK_DXOUT: C21.2, U5.6 (PD1), Y3.1
/JLINK_USB_RENUM: R36.2, U5.38 (PA15)
/LED0: R1.2, U1.14 (PE17/CSI_D13/LCD_D19)
/LED_STLINK: D2.1 (K), U5.30 (PA9)
/OTG_DM: J3.A7 (D-), R16.1, U1.110 (USB-DM)
/OTG_DP: J3.A6 (D+), R17.1, U1.111 (USB-DP)
/RESET: C45.2, R45.1, U1.99 (RESET)
/SDC0_CLK: J1.5 (CLK), U1.105 (PF2/SDC0_CLK/UART0_TX)
/SDC0_CMD: J1.3 (CMD), RN3.2 (R2.1), U1.103 (PF3/SDC0_CMD/JTAG_DO1)
/SDC0_D0: J1.7 (DAT0), RN3.1 (R1.1), U1.106 (PF1/SDC0_D0/JTAG_DI1)
/SDC0_D1: J1.8 (DAT1), R5.2, U1.107 (PF0/SDC0_D1/JTAG_MS1)
/SDC0_D2: J1.1 (DAT2), RN3.4 (R4.1), U1.101 (PF5/SDC0_D2/JTAG_CK1)
/SDC0_D3: J1.2 (DAT3/CD), RN3.3 (R3.1), U1.102 (PF4/SDC0_D3/UART0_RX)
/SPI0_CLK: U1.53 (PC1/SDC2_CMD/SPI_CLK), U6.6 (CLK)
/SPI0_CS: R41.2, U1.54 (PC2/SDC2_RST/SPI_CS)
/SPI0_MISO: U1.52 (PC0/SDC2_CLK/SPI_MISO), U6.2 (DO(IO1))
/SPI0_MOSI: U1.55 (PC3/SDC2_D0/SPI_MOSI), U6.5 (DI(IO0))
/ST_SWCLK: J4.2, U5.37 (PA14)
/ST_SWDIO: J4.1, U5.34 (PA13)
/T_JTCK_SWCLK: R28.1, U5.15 (PA5), U5.26 (PB13)
/T_JTMS_SWDIO: R20.2, R29.1, U5.27 (PB14)
/T_SWDIO_IN: R20.1, U5.25 (PB12)
/UART0_RX: R38.1, U1.49 (PB9/TWI1_SDA/UART0_RX/PB_EINT9)
/UART0_TX: R37.2, U1.48 (PB8/TWI1_SCK/UART0_TX/PB_EINT8)
/UART_DM: J2.A7 (D-), J2.B7 (D-), U4.8 (VD-)
/UART_DP: J2.A6 (D+), J2.B6 (D+), U4.7 (VD+)
/VRA1: C32.2, U1.117 (VRA1)
/VRA2: C33.2, R40.1, U1.118 (VRA2)
/WL_SDIO_CLK: RN2.3 (R3.1), U1.5 (PG0/SDC1_CLK/PG_EINT0), U7.17 (SD_CLK)
/WL_SDIO_CMD: RN2.4 (R4.1), U1.4 (PG1/SDC1_CMD/PG_EINT1), U7.16 (SD_CMD)
/WL_SDIO_D0: RN2.2 (R2.1), U1.3 (PG2/SDC1_D0/PG_EINT2), U7.18 (SD_D0)
/WL_SDIO_D1: RN2.1 (R1.1), U1.2 (PG3/SDC1_D1/PG_EINT3), U7.19 (SD_D1)
/WL_SDIO_D2: RN1.2 (R2.1), U1.1 (PG4/SDC1_D2/PG_EINT4), U7.14 (SD_D2)
/WL_SDIO_D3: RN1.1 (R1.1), U1.128 (PG5/SDC1_D3/PG_EINT5), U7.15 (SD_D3)
/WL_UART_RX: U1.40 (PB1/UART2_RX/PB_EINT1), U7.42 (UART_OUT)
/WL_UART_TX: U1.39 (PB0/UART2_TX/PB_EINT0), U7.43 (UART_IN)
GND: AE1.2 (Shield), C1.2, C2.2, C3.2, C4.1, C5.1, C6.1, C10.1, C11.1, C12.1, C13.2, C14.2, C15.1, C16.1, C17.1, C18.1, C19.1, C20.1, C21.1, C22.2, C23.2, C24.2, C25.2, C26.1, C27.1, C28.1, C29.1, C30.1, C31.1, C32.1, C33.1, C34.1, C35.1, C36.2, C37.1, C38.1, C40.1, C41.1, C42.1, C43.1, C44.1, C45.1, C46.2, C47.2, C48.2, C49.2, C50.2, C51.2, C52.2, C53.2, C54.2, C55.2, C56.2, C57.2, C58.2, C59.2, C60.2, C61.2, C62.2, C63.2, C64.2, C65.2, C66.2, C67.1, C68.2, C69.2, C72.2, C73.2, D1.2 (A2), D4.1 (K), J1.6 (VSS), J1.9 (SHIELD), J2.A1 (GND), J2.A12 (GND), J2.B1 (GND), J2.B12 (GND), J2.S1 (SHIELD), J3.A1 (GND), J3.A12 (GND), J3.B1 (GND), J3.B12 (GND), J3.S1 (SHIELD), J4.3, J5.2, J5.MP (MountPin), J6.1, R3.2, R9.2, R10.2, R11.2, R12.1, R13.1, R14.1, R15.1, R19.2, R21.2, R23.1, R27.2, R34.2, R39.1, R40.2, R42.2, U1.116 (AGND), U1.129 (EGND), U2.1 (GND3), U2.4 (AGND), U2.6 (GND2), U2.13 (GND1), U2.18 (GND4), U2.25 (PAD), U3.2 (GND), U4.2 (GND), U4.17 (GND), U5.8 (VSSA), U5.20 (PB2), U5.23 (VSS), U5.35 (VSS), U5.47 (VSS), U6.4 (GND), U7.1 (GND), U7.3 (NC), U7.20 (GND), U7.31 (GND), U7.33 (GND), U7.36 (GND), U7.41 (GND), U7.44 (UART_CTS), U8.2 (GND), Y2.2, Y2.4, Y3.2
unnamed: AE1.1 (A), U7.2 (ANT)
unnamed: D2.2 (A), R35.1
unnamed: C71.1, C72.1, C73.1, D3.2 (A), L4.2, R2.1
unnamed: D4.2 (A), R1.1
unnamed: J2.A5 (CC1), R12.2
unnamed: J2.B5 (CC2), R13.2
unnamed: J3.A5 (CC1), R14.2
unnamed: J3.B5 (CC2), R15.2
unnamed: F2.1, J5.1
unnamed: J5.3, R28.2
unnamed: J5.4, R29.2
unnamed: F3.2, J6.2
unnamed: Q1.1 (B), R33.2, R34.1, R36.1
unnamed: Q1.2 (E), R30.2
unnamed: RN1.3 (R3.1), U7.13 (WL_HOST_WAKE)
unnamed: RN1.4 (R4.1), U7.12 (WL_DSI)
unnamed: C44.2, U1.123 (HPVCCBP)
unnamed: C34.2, U1.97 (RTC-VIO)
unnamed: R39.2, U1.73 (SZQ)
unnamed: C7.1, R6.2, R9.1, U2.14 (FB1)
unnamed: C8.1, R7.2, R10.1, U2.5 (FB2)
unnamed: C9.1, R8.2, R11.1, U2.2 (FB3)
unnamed: L1.1, U2.12 (LX1)
unnamed: L2.1, U2.7 (LX2)
unnamed: L3.1, U2.24 (LX3)
unnamed: C2.1, U3.4 (BP)
unnamed: R37.1, U4.5 (RXD)
unnamed: R38.2, U4.4 (TXD)
unnamed: C15.2, U4.6 (V3)
unnamed: R23.2, U5.44 (BOOT0)
unnamed: C19.2, R18.2, U5.7 (NRST)
unnamed: R26.2, R27.1, U5.10 (PA0)
unnamed: R22.2, U5.39 (PB3)
unnamed: R19.1, U5.2 (PC13)
unnamed: R21.1, U5.3 (PC14)
unnamed: R46.2, U7.34 (BT_DIS)
unnamed: C70.1, U8.1 (BS)
unnamed: C71.2, R2.2, R3.1, U8.3 (FB)
unnamed: C70.2, L4.1, U8.6 (LX)
SVREF: C38.2, C39.1, R42.1, R44.2, U1.63 (SVREF1), U1.71 (SVREF0)
VBUS: F1.2, J2.A4 (VBUS), J2.A9 (VBUS), J2.B4 (VBUS), J2.B9 (VBUS), J3.A4 (VBUS), J3.A9 (VBUS), J3.B4 (VBUS), J3.B9 (VBUS)

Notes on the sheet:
PWR
JLINK
调到1.15V 左右
WIFI
V-IO
正反插功能不同
V-DRAM
使用VBUS供电, IO电平3.3V
V-SYS
必须上拉DSI才能连到
V3S
FLASH
USB-UART
V-CPU
PA2: TXD PA3: RXD PB13: SWCLK PB14: SWDIO PB0: NRST

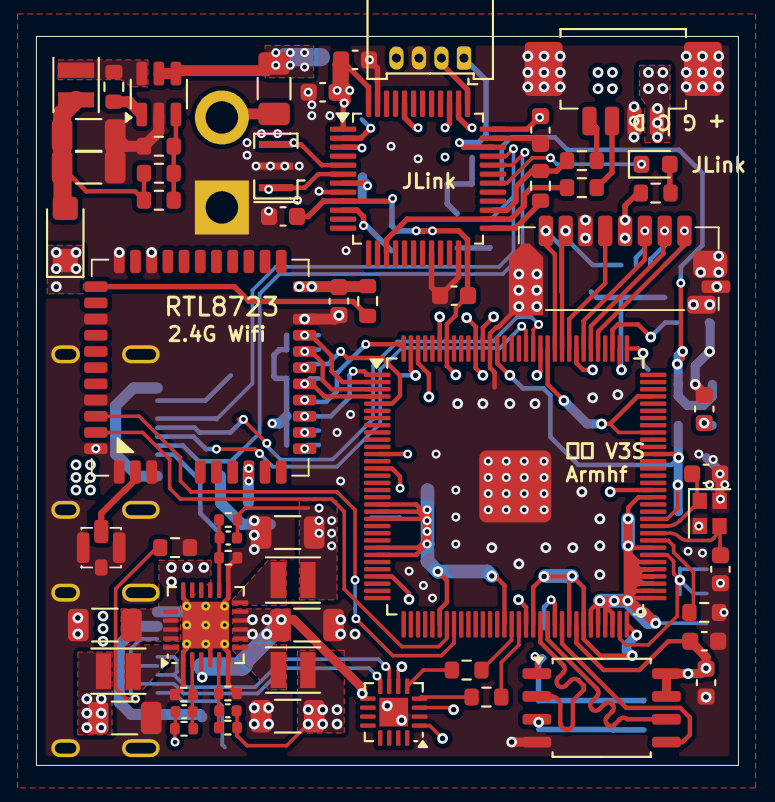
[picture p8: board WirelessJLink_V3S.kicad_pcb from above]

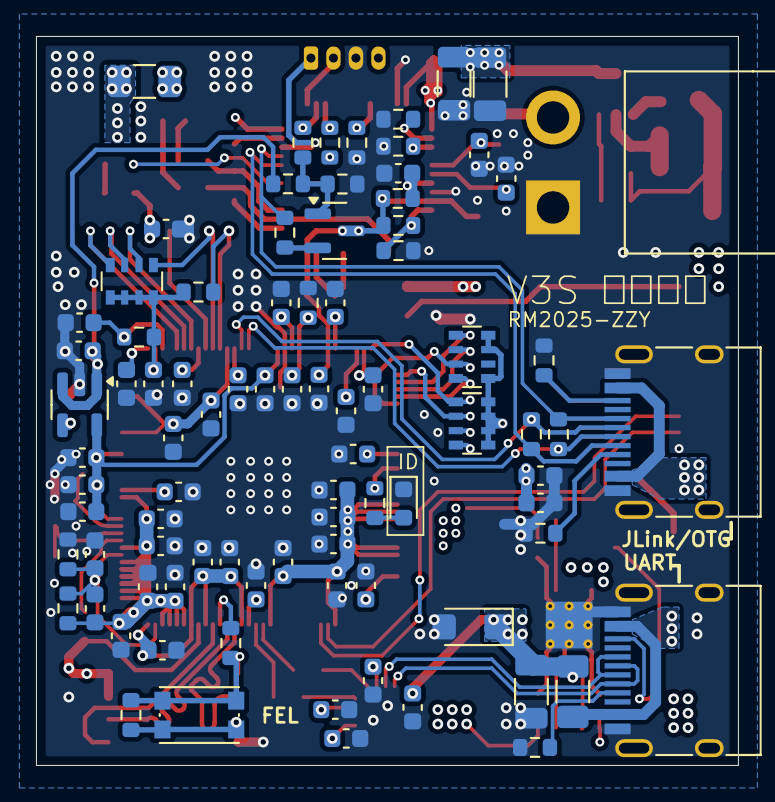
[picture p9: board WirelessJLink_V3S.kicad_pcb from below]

Board: 4 copper layers, 39.0 x 40.5 mm, 147 parts (87 on the bottom side), 90 nets.

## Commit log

2025-08-06 Add Hardware & References
    [WirelessJLink_V3S.kicad_pcb, WirelessJLink_V3S.kicad_sch]
2025-08-19 编译教程引入
2025-08-29 Clarify power supply color coding in README
    Updated the power supply section to clarify the color coding for internal and external device power.
